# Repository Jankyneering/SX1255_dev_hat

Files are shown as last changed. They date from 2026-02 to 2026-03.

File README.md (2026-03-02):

# SX1255 Dev Hat

A Simple Raspberry Pi Zero shield with the SX1255 RF transceiver chip.  
[`v0.1`](https://github.com/Jankyneering/SX1255_dev_hat/releases/tag/v0.1) based on [M17](https://github.com/M17-Project/SX1255_HAT-hw/blob/main/README.md)'s design, and Semtech's application schematic in the [SX1255 Datasheet](https://www.semtech.com/uploads/documents/sx1255.pdf).

## Production files

Production files for this hat can be found in the [releases](https://github.com/Jankyneering/SX1255_dev_hat/releases). Upload these files to your favorite PCB manufacturer, and make sure to specify the correct board thickness (1.6mm).  
We ordered a batch from JLCPCB and had them assemble the components.

> v0.1 is not intended for production use, but rather as a development platform for testing the SX1255 chip and its software support. It is not optimized for performance, power consumption, RF impedance, and may have some design flaws. Use at your own risk.

## License & Acknowledgements

Made with ❤️, lots of ☕️, and lack of 🛌  
Published under CreativeCommons BY-SA 4.0

  
This work is licensed under a [Creative Commons Attribution-ShareAlike 4.0 International License](http://creativecommons.org/licenses/by-sa/4.0/).

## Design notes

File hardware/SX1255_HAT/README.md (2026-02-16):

# SX1255_HAT

Raspberry Pi Zero shield with the SX1255 RF transceiver chip.  
Based on [M17](https://github.com/M17-Project/SX1255_HAT-hw/blob/main/README.md)'s design.



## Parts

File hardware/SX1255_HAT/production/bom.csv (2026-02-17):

Designator | Footprint | Quantity | Value | LCSC Part #
C1, C16, C2, C3, C4 | 0603 | 5 | 10n | C0603C103M4REC7411
C10, C13, C5, C6, C7, C8, C9 | 0603 | 7 | 100n | 06035G104ZAT2A
C11 | 0603 | 1 | 33p | VJ0603A330KXAPW1BC
C12 | 0603 | 1 | 27p | AC0603JRNPO9BN270
C14, C15 | 0603 | 2 | 6.8p | 06035G104ZAT2A
IC1 | QFN50P500X500X80-33N-D | 1 | SX1255 | SX1255IWLTRT
J1 | U.FL_Molex_MCRF_73412-0110_Vertical | 1 | TX | RF2-04A-T-00-50-G
J2 | U.FL_Molex_MCRF_73412-0110_Vertical | 1 | RX | RF2-04A-T-00-50-G
JP2 | SolderJumper-2_P1.3mm_Open_RoundedPad1.0x1.5mm | 1 | WP
L1 | 0603 | 1 | 82n | AISC-0603-R082J-T
L2 | 0603 | 1 | 39n | AISC-0603-R039J-T
L3 | 0603 | 1 | 33n | AISC-0603-R039J-T
R1, R2, R3, R4, R5, R6, R7 | 0603 | 7 | 100R | CRCW0603100RFKECC
R10, R8, R9 | 0603 | 3 | 3K9 | CRCW06033K9FKECC
U1 | SOIC-8_3.9x4.9mm_P1.27mm | 1 | 24LC256
Y1 | Crystal_SMD_2016-4Pin_2.0x1.6mm | 1 | 32MHz | ECS-TXO-20CSMV4-320-AY-TR

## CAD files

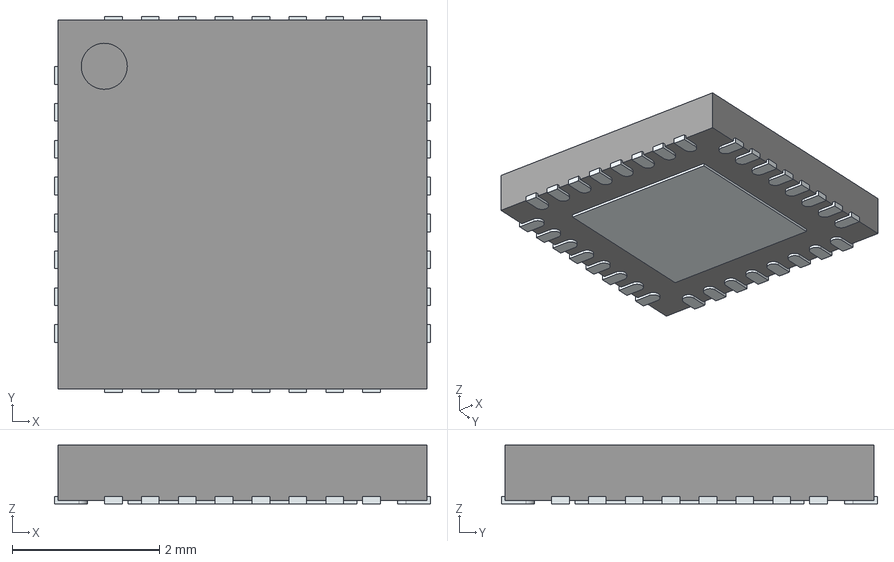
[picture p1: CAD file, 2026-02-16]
hardware/SX1255_HAT/parts/SX1255IWLTRT.stp
5.10 x 5.10 x 0.8 mm
ThermalPin
PinsArrayLR
PinsArrayTB

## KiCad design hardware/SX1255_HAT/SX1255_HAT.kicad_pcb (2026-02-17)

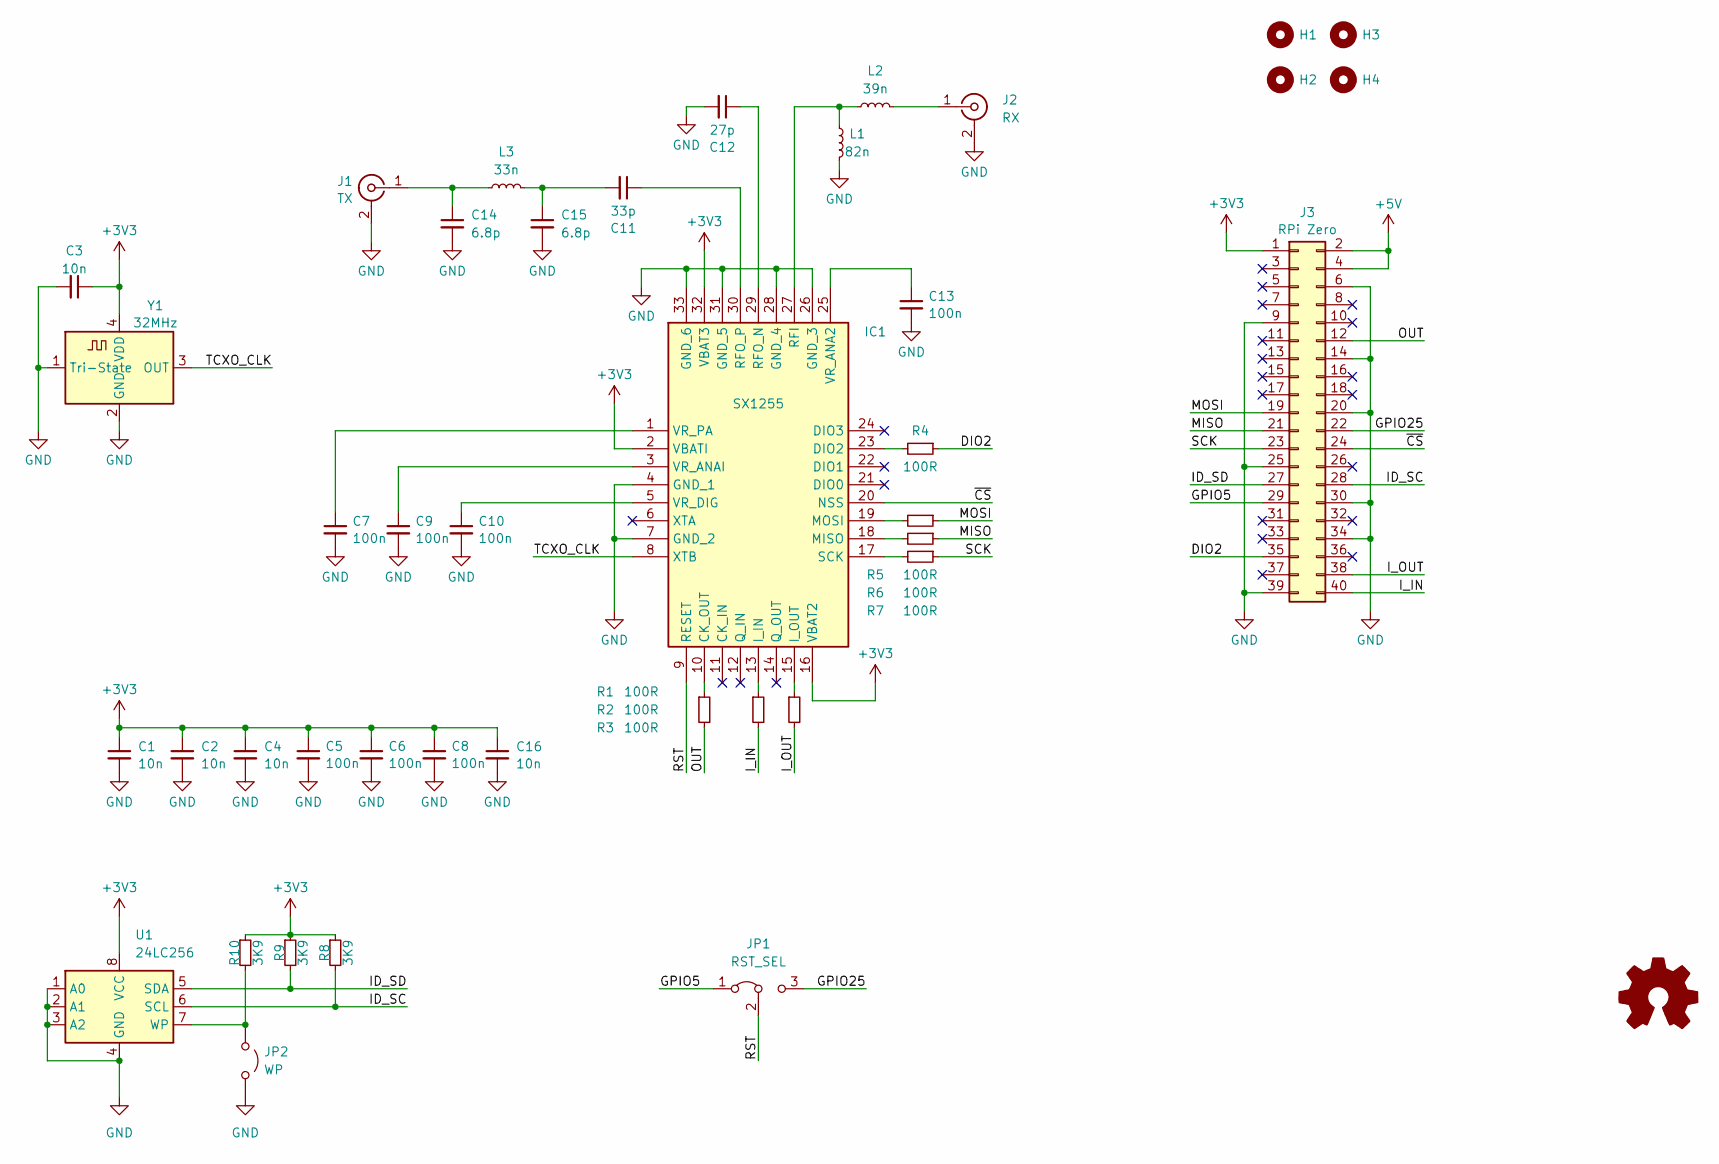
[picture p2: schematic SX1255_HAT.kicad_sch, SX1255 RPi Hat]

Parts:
C1, C2, C3, C4, C16: 10n; C_0603_1608Metric; MPN C0603C103M4REC7411
C5, C6, C7, C8, C9, C10, C13: 100n; C_0603_1608Metric; MPN 06035G104ZAT2A
C11: 33p; C_0603_1608Metric; MPN VJ0603A330KXAPW1BC
C12: 27p; C_0603_1608Metric; MPN AC0603JRNPO9BN270
C14, C15: 6.8p; C_0603_1608Metric; MPN 06035G104ZAT2A
H1, H2, H3, H4: MountingHole; MountingHole_2.7mm_M2.5_DIN965
IC1: SX1255; QFN50P500X500X80-33N-D; MPN SX1255IWLTRT
J1: TX; U.FL_Molex_MCRF_73412-0110_Vertical; MPN RF2-04A-T-00-50-G
J2: RX; U.FL_Molex_MCRF_73412-0110_Vertical; MPN RF2-04A-T-00-50-G
J3: RPi Zero; PinSocket_2x20_P2.54mm_Vertical
JP1: RST_SEL; SolderJumper-3_P1.3mm_Bridged12_RoundedPad1.0x1.5mm_NumberL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
JP2: WP; SolderJumper-2_P1.3mm_Open_RoundedPad1.0x1.5mm
L1: 82n; L_0603_1608Metric; MPN AISC-0603-R082J-T
L2: 39n; L_0603_1608Metric; MPN AISC-0603-R039J-T
L3: 33n; L_0603_1608Metric; MPN AISC-0603-R039J-T
R1, R2, R3, R4, R5, R6, R7: 100R; R_0603_1608Metric; MPN CRCW0603100RFKECC
R8, R9, R10: 3K9; R_0603_1608Metric; MPN CRCW06033K9FKECC
SYM1: Logo_Open_Hardware_Small; OSHW-Logo2_7.3x6mm_SilkScreen
U1: 24LC256; SOIC-8_3.9x4.9mm_P1.27mm
Y1: 32MHz; Crystal_SMD_2016-4Pin_2.0x1.6mm; MPN ECS-TXO-20CSMV4-320-AY-TR

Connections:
+3V3: C1.1, C2.1, C3.1, C4.1, C5.1, C6.1, C8.1, C16.1, IC1.2 (VBATI), IC1.16 (VBAT2), IC1.32 (VBAT3), J3.1, R8.1, R9.1, R10.1, U1.8 (VCC), Y1.4 (VDD)
+5V: J3.2, J3.4
/DIO2: J3.35, R4.1
/GPIO5: J3.29, JP1.1 (A)
/GPIO25: J3.22, JP1.3 (B)
/ID_SC: J3.28, R8.2, U1.6 (SCL)
/ID_SD: J3.27, R9.2, U1.5 (SDA)
/I_IN: J3.40, R2.2
/I_OUT: J3.38, R3.2
/MISO: J3.21, R6.1
/MOSI: J3.19, R5.1
/OUT: J3.12, R1.2
/RST: IC1.9 (RESET), JP1.2 (C)
/SCK: J3.23, R7.1
/TCXO_CLK: IC1.8 (XTB), Y1.3 (OUT)
/~CS: IC1.20 (NSS), J3.24
GND: C1.2, C2.2, C3.2, C4.2, C5.2, C6.2, C7.2, C8.2, C9.2, C10.2, C12.2, C13.2, C14.2, C15.2, C16.2, IC1.4 (GND_1), IC1.7 (GND_2), IC1.26 (GND_3), IC1.28 (GND_4), IC1.31 (GND_5), IC1.33 (GND_6), J1.2 (Ext), J2.2 (Ext), J3.6, J3.9, J3.14, J3.20, J3.25, J3.30, J3.34, J3.39, JP2.2 (B), L1.1, U1.1 (A0), U1.2 (A1), U1.3 (A2), U1.4 (GND), Y1.1 (Tri-State), Y1.2 (GND)
unnamed: C11.2, C15.1, L3.1
unnamed: IC1.10 (CK_OUT), R1.1
unnamed: IC1.23 (DIO2), R4.2
unnamed: IC1.13 (I_IN), R2.1
unnamed: IC1.15 (I_OUT), R3.1
unnamed: IC1.18 (MISO), R6.2
unnamed: IC1.19 (MOSI), R5.2
unnamed: IC1.27 (RFI), L1.2, L2.2
unnamed: C12.1, IC1.29 (RFO_N)
unnamed: C11.1, IC1.30 (RFO_P)
unnamed: IC1.17 (SCK), R7.2
unnamed: C13.1, IC1.25 (VR_ANA2)
unnamed: C9.1, IC1.3 (VR_ANAI)
unnamed: C10.1, IC1.5 (VR_DIG)
unnamed: C7.1, IC1.1 (VR_PA)
unnamed: C14.1, J1.1 (In), L3.2
unnamed: J2.1 (In), L2.1
unnamed: JP2.1 (A), R10.2, U1.7 (WP)

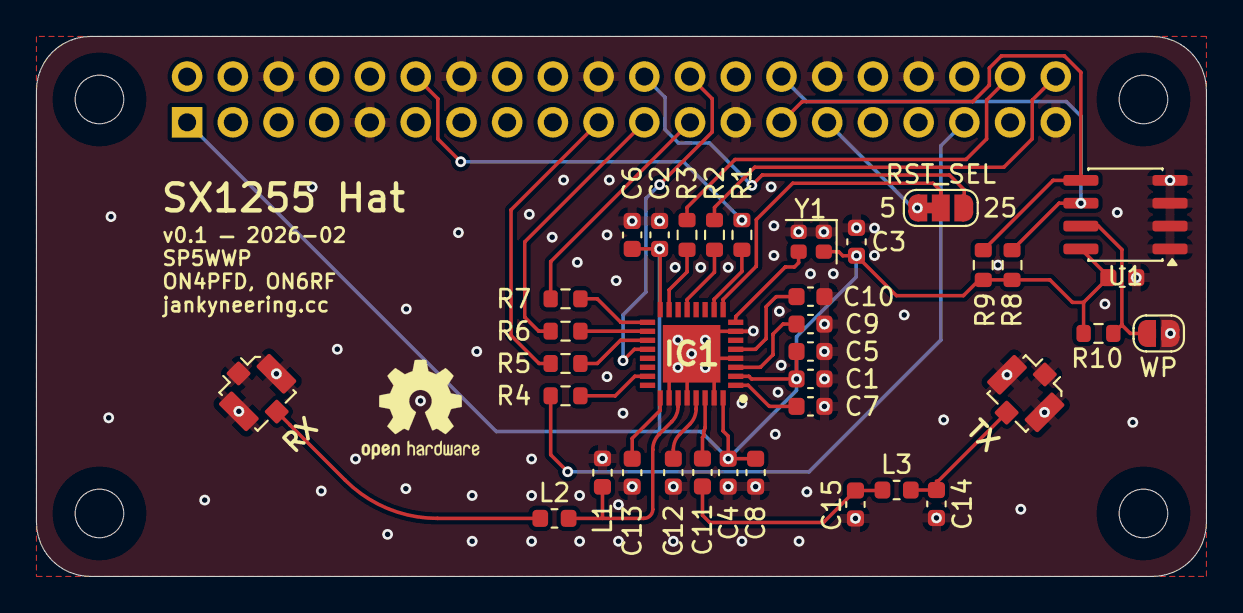
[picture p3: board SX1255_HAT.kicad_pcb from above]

Board: 2 copper layers, 65.0 x 30.0 mm, 42 parts (1 on the bottom side), 35 nets.

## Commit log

2026-02-16 added sources
    [SX1255IWLTRT.stp, SX1255_HAT.kicad_pcb, SX1255_HAT.kicad_sch]
2026-02-16 Added Tx filters, EEPROM, modified for soapy-sx compat
    [SX1255_HAT.kicad_pcb, SX1255_HAT.kicad_sch]
2026-02-16 Added decoupling for EEPROM and WP pin
    [SX1255_HAT.kicad_pcb, SX1255_HAT.kicad_sch]
2026-02-16 added DRU, modified component placement, updated schematic
    [SX1255_HAT.kicad_pcb, SX1255_HAT.kicad_sch]
2026-02-17 added fabrication files
    [SX1255_HAT.kicad_pcb, bom.csv, designators.csv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]

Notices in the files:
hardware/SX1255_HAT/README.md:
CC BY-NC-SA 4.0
